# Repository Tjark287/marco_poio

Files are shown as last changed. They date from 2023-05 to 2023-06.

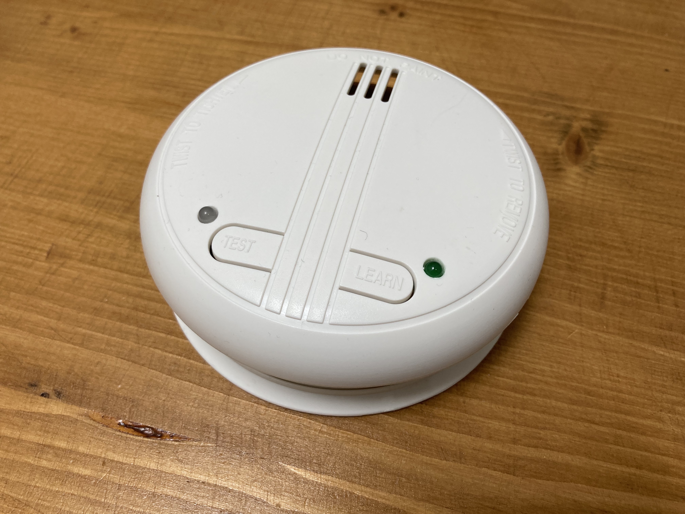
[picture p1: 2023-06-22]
Hardware/POI_Prototype.jpeg

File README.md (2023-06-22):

# Marco POIo Project

The goal of the "Marco POIo" project is to assist blind people in navigating back to a known spot where a point of interest (POI) has been left behind. The wearable device provides haptic feedback in the form of vibrations to guide the user towards the POI when the user presses a button. Additionally, the stationary device emits a beeping sound when the user gets within a specified distance of the POI. Both devices are equipped with GPS, a microcontroller unit (MCU) and an ISM transceiver. The wearable device also includes a magnetic sensor to act as a compass, helping the user to navigate towards the stationary device.

**Software overview:**
The main.c has two modes depending on loading the POI or the WEARABLE. Please use either the #define IS_POI or IS_WEARABLE depending on which device should be programmed. We used the minmea library by Kosma Moczek for nmea string decoding and partially ported the RFM69 library by Felix Rusu (LowPowerLab.com) to C for the ISM communications.

**Disclaimer:**
Please note that the project was created for a UNI project and is still in its early development phase. We do not recommend relying on the system as is for critical navigation purposes. We wish to improve on many areas, especially creating a more robust system for ISM communications, processing more of the available GPS NMEA sentences (currently only RMC processed) for a more stable location and a routine to calibrate the compass for more percise heading measurement as well as a generally improved system design.

**How To Build your own:**

*Hardware Components required:*
- Main Processor: STM32F411CEU - can vary, not much processing power is required
- GPS Receiver: L76-M33
- Radio: RFM69HW
- Antenna: helical antenna used, any 868MHz antenna with SWR<2 is good
- Magnetometer IC: MMC34160PJ
- 3V3 vibration motor
- 2x 2n7000 MOSFET
- LEDSs + resistors
- ST-Link V2 programmer

Please refer to the schematic for details.

## Prototype devices
For testing and in-class presentation we made 2 crude prototypes of our devices:
*POI:*
POI prototype
*Wearable:*
WEARABLE prototype

## How to use Marco POIo
The "Marco POIo" device consists of two parts: the Point of Interest (POI) and the WEARABLE. The POI is placed at a specific location, such as your clothing at the beach, while the WEARABLE is carried with you, for example, when you go swimming. The goal of the device is to help you find the POI once you come out of the water. Here is a detailed guide on how to use the device:

*1. Activating the POI:*
- Locate the POI and make sure it is turned on.
- Press the special power button on the POI. This will play a unique activation sound and activate the device.

*2. Preparing the WEARABLE before swimming:*
- Take the WEARABLE with you for swimming.
- Attach it as described.

*3. Using the WEARABLE during the return:*
- After swimming, when you come out of the water, press the button on the WEARABLE to start navigation mode.
- The WEARABLE starts vibrating to provide feedback.
- Hold the WEARABLE horizontally and point it in different directions to feel the vibration.
- The vibration becomes stronger when you align the WEARABLE towards your POI.
- Move in the direction where the vibration is strongest to find your way back to the POI.

*4. Approaching the POI:*
- As you get closer to the POI and are only a few meters away, the POI automatically starts beeping to help you locate it.

*5. Arrival and turning off the POI:*
- Once you reach the POI, press the button on it.
- This will stop the beeping, and the POI will automatically turn off.

Note: Make sure to activate the POI and Wearable, wait for the ready-beep and only then leave your spot. Please note that the device is still in the development phase and is not recommended for critical navigation situations. Do not rely solely on this device; use it as a support for your orientation.

## Design 
The development of the wearable focuses on finding the best wearing position, preferably on the wrist with a wrist strap or Velcro for ease of use. The wearable should be inexpensive and have Braille on the outside describing which way the device should be properly attached to the arm. It provides tactile feedback for navigation and a user-friendly interface.
The challenge is to develop a waterproof housing that is also light enough and does not interfere with signal transmission. Special materials, seals and coatings are being considered to prevent water ingress and ensure device performance.
Work is ongoing to develop and optimize the design to ensure the wearable is practical to implement and meets requirements. Consideration will be given to wearing position, accessibility through Braille, tactile feedback, water resistance, and ease of use. The goal is to create a wearable that provides an effective navigation solution for blind people while being comfortable and easy to use.

### Mockup Idea 1:
In this design idea, the wearable is attached to an arm holder by simply clicking it into the holder. After swimming, the wearable can be removed from the holder by a mechanical mechanism. It is activated by pressing a button. The elongated wearable then moves in front of itself like a blind stick. More intense vibration signals the user which direction to go.

### Mockup Idea 2:
The second design idea involves attaching the wearable to a wristwatch. The case of the wearable can be easily attached to any watch band. Braille on the case clarifies where the front and back are located. Once on the water, you hold your arm in front of you as if you were looking at the watch and press the button on the side of the case. Intense vibration signals the user which way to go.

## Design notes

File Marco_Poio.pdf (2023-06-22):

# ASSIST HEIDI

# Final Presentation

# MARCO POIo

Matthias Finding | | | ew21b031@technikum-wien.de
David Schmutz | | | ew21b083@technikum-wien.de
Tjark Neumann | | | if22x027@technikum-wien.de

### https://github.com/Tjark287/marco_poio

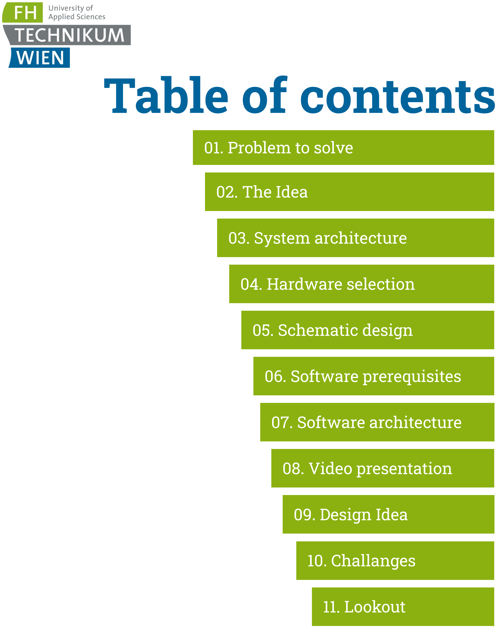
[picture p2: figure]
Table of contents; 01. Problem to solve; 02. The Idea; 03. System architecture; 04. Hardware selection; 05. Schematic design; 06. Software prerequisites; 07. Software architecture; 09. Design Idea; 08. Video presentation; 10. Challanges; 11. Lookout

# NEVER GET LOST SWIMMING AGAIN

### -MARCO POIO

# What is the problem to solve?

While blind people oftentimes develop amazing navigational skills on land,

### when they enter a body of water it becomes very hard to get an idea of

where you are due to currents carrying you away in unexpected ways.

# NEVER LOSE YOUR CLOTHE AGIAN

### -MARCO POIO

# How to solve the problem?

## The Idea

### 2-piece device:

### - Point of interest (POI) - Wearable

### Navigate with Wearable device to the POI device

# System architecture

## Overview

Wearable

GPS

B-Sensor

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
GPS receiver

Compass IC

ISM transceiver

Microcontroller

Interface devices
(Vibration-Motor, Button)

GPS receiver

ISM transceiver

Microcontroller

Interface devices
(Vibration-Motor, Button)

# Hardware selection

## Overview

To implement our system architecture, we chose the following components:

- GPS: Quectel L76-M33 GPS receiver
- ISM: HopeRF RFM69HW 868MHz +20dBm ISM transceiver
- Compass: MMC34160PJ ±16 Gauss magnetic sensor
- MCU: STM32F411CEU 100MHz ARM Cortex M4

All hardware components are 3V compatible

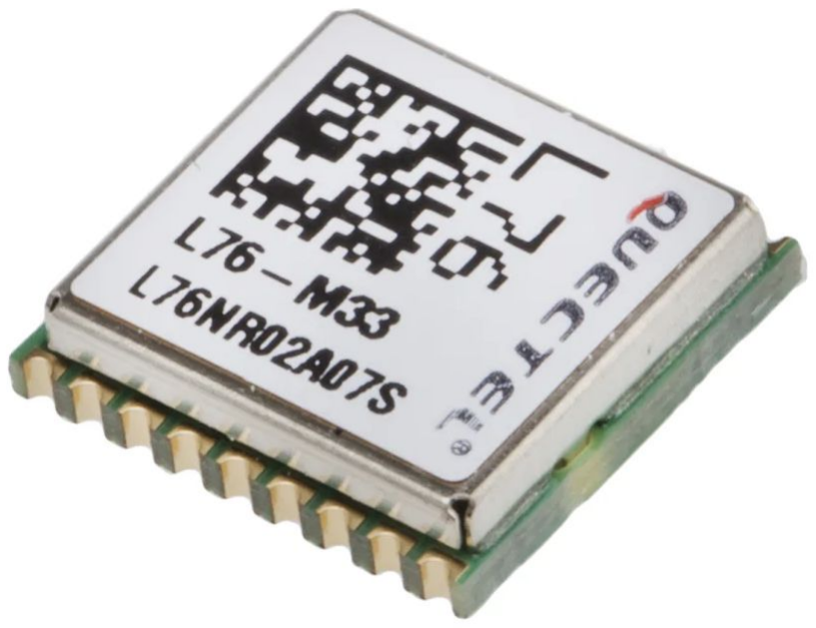
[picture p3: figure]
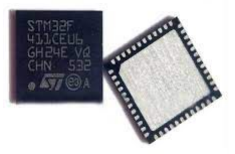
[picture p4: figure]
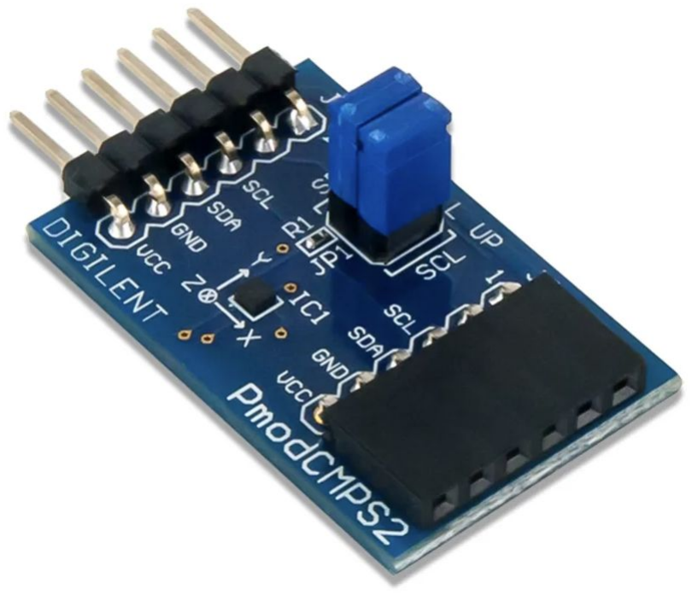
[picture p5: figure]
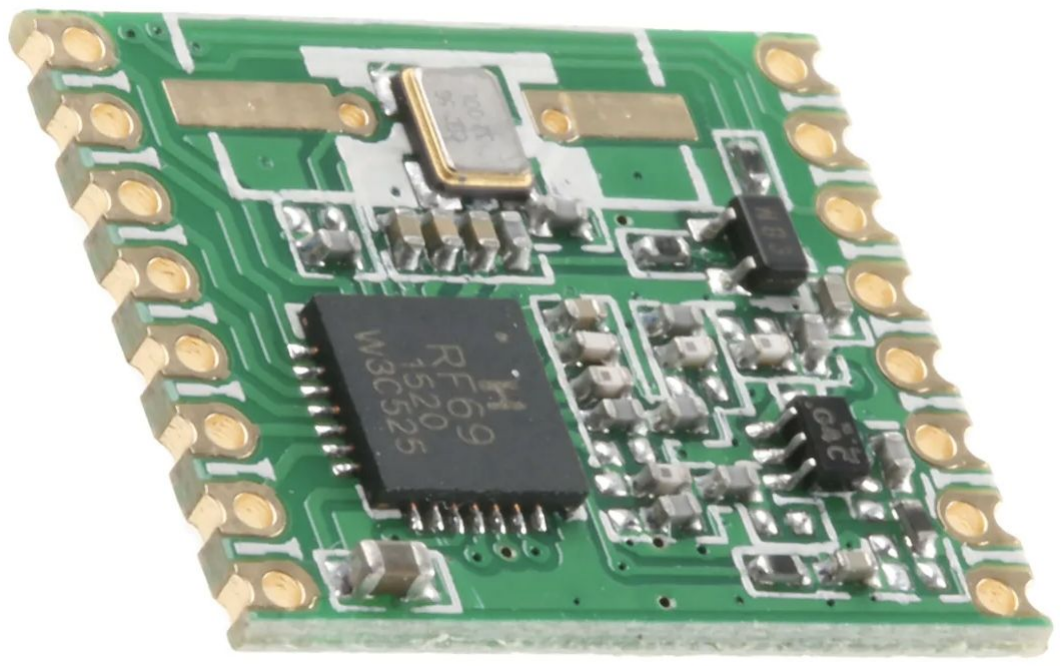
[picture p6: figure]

# Schematic design

## Overview

The schematic describes the connectivity of all hardware components in our design. The main interconnects are:

- GPS: UART interface to STM32 MCU (PB3, receive only)
- ISM: SPI interface + control pins to STM32 MCU (PA1, PA4, PA5, PA6, PA7)
- Compass: I2C interface to STM32 MCU (PB6, PB7)
- User interface:
- Pushbutton to interrupt pin on STM32 (PB1)
- PWM control of vibration-motor from STM32 (PA10)
- GPIO output for Buzzer activation from STM32 (PB9)

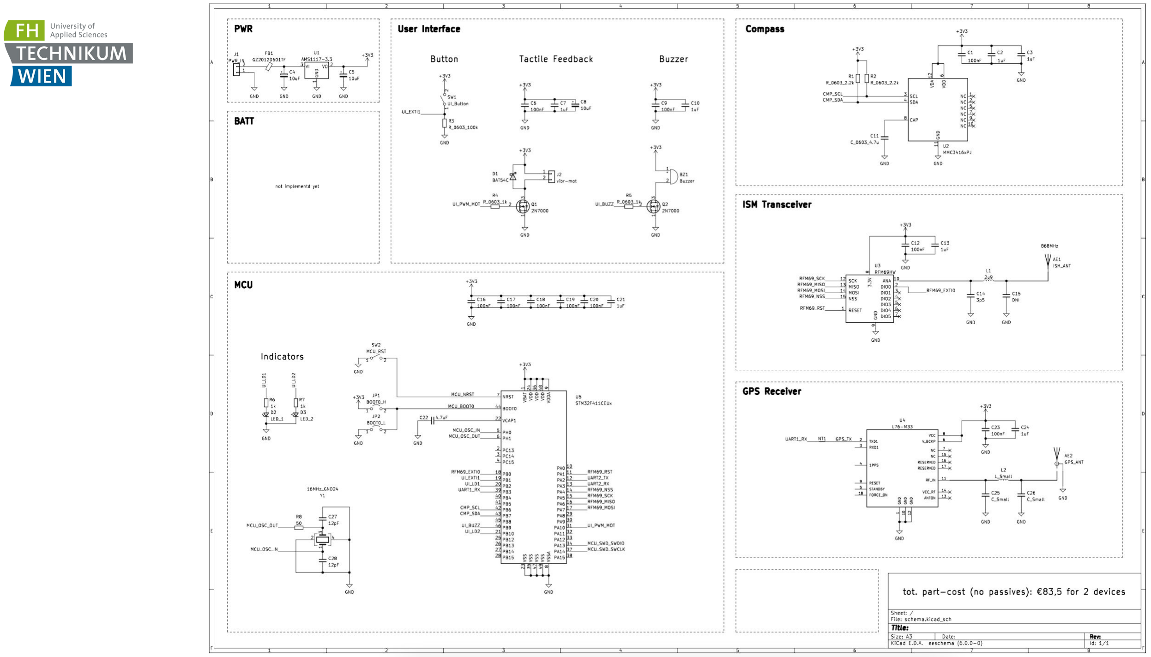
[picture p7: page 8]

# Software prerequisites

## Overview

External libraries used:

- minmea.c for GPS message decoding
- RFM69.c (ported from C++ to C) to handle the RF communications

Libraries created from scratch:

- helpHeidi.c
- gps.c
- compass.c

# Software architecture

## Overview

The architecture of the entire system is event- and timer-based. Three main callbacks were implemented:

- HAL_GPIO_EXTI_Callback: handles pushbutton input and interrupts from the RFM69 module
- HAL_UART_RxCpltCallback: handles information received from the GPS module
- HAL_TIM_PeriodElapsedCallback: handles events timed by the main 10Hz system timer

The main loop then carries out all data-send-operations and setting of vibration-motor and buzzer depending on the system state.

To further simplify the coding process, the target device and thereby the system behavior can be defined with a #define statement at the beginning of the code with:
#define IS_POI or #define IS_WEARABLE

# Video

## Prototype

# Design

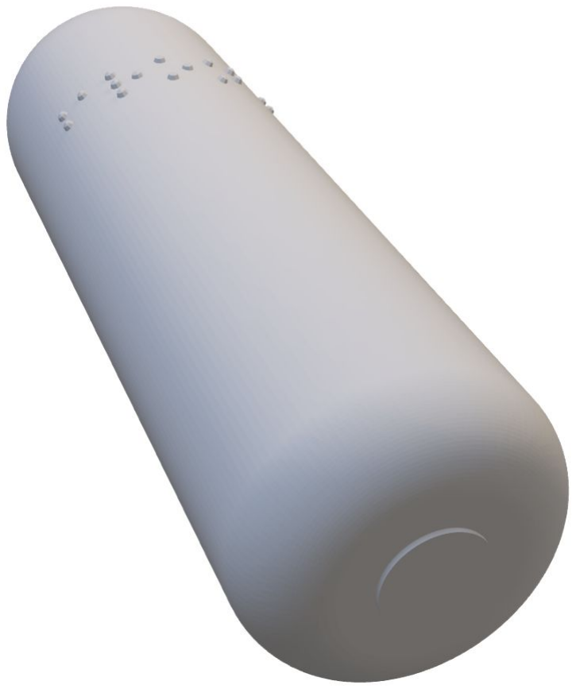
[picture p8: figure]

## Prerequisites

Accessibility (Cheap)

Braille Integration

Tactile Feedback

Waterproof

User-Friendly Interface

# Design

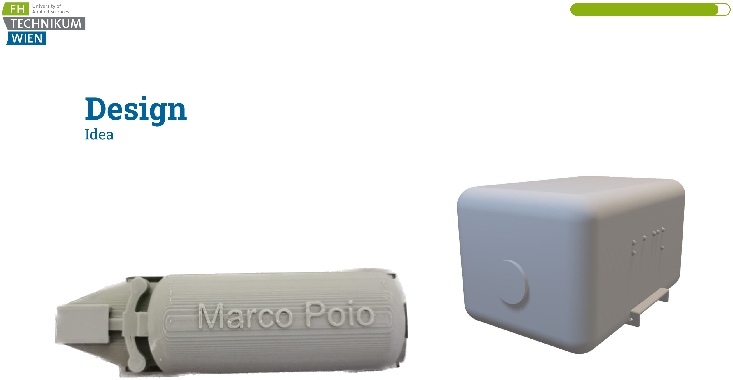
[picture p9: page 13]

## Idea

# Challenges

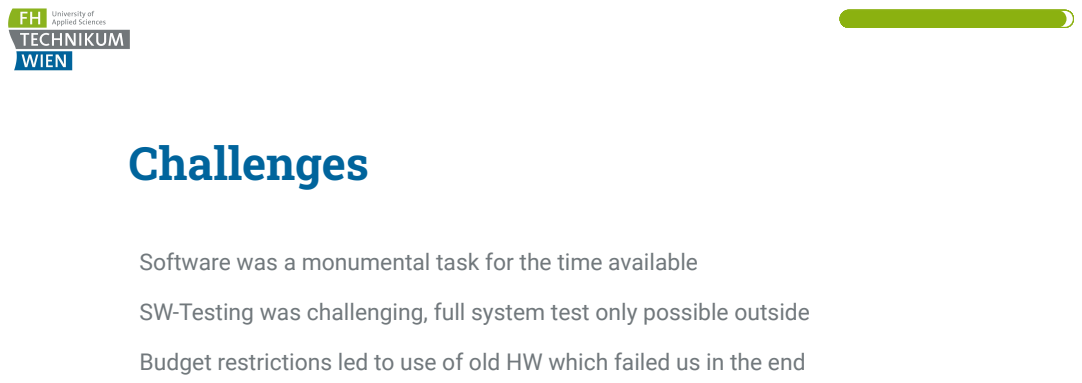
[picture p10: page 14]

Software was a monumental task for the time available

SW-Testing was challenging, full system test only possible outside

Budget restrictions led to use of old HW which failed us in the end

# Lookout

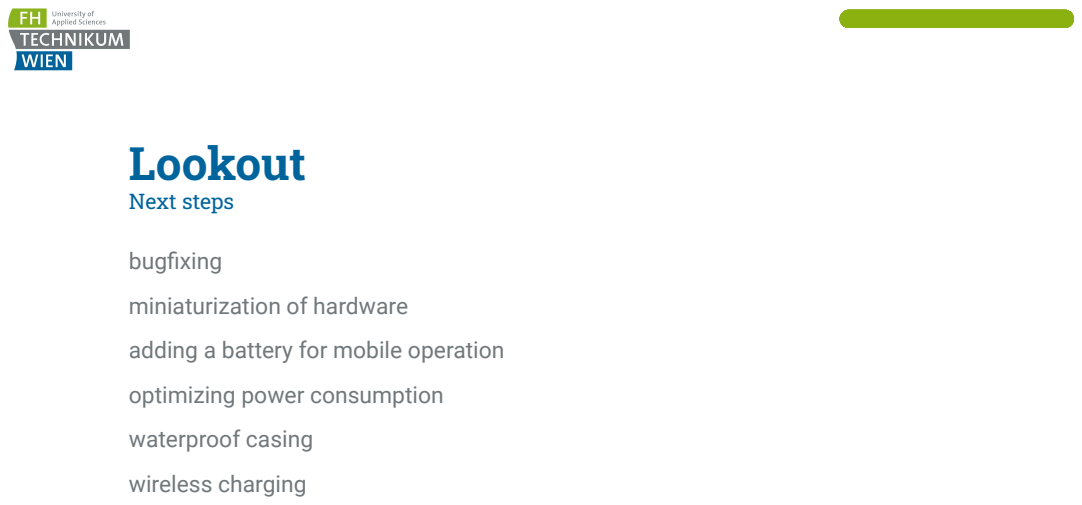
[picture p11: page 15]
Next steps; bugfixing; waterproof casing; wireless charging

miniaturization of hardware

adding a battery for mobile operation

optimizing power consumption

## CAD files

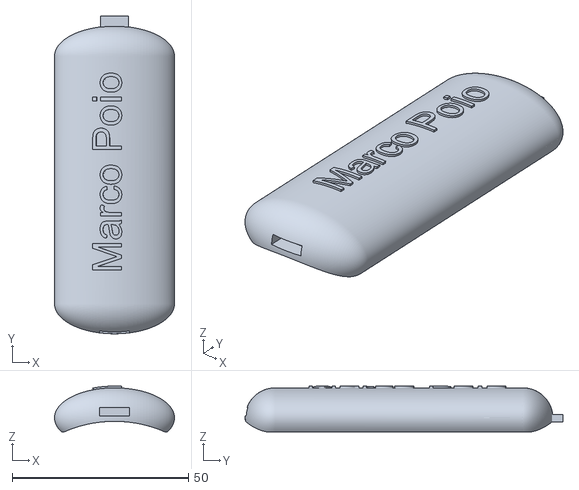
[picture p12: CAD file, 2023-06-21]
Design/Mockup Final Version 1/Marcopoio handheld.stl
34.0 x 90.0 x 13.0

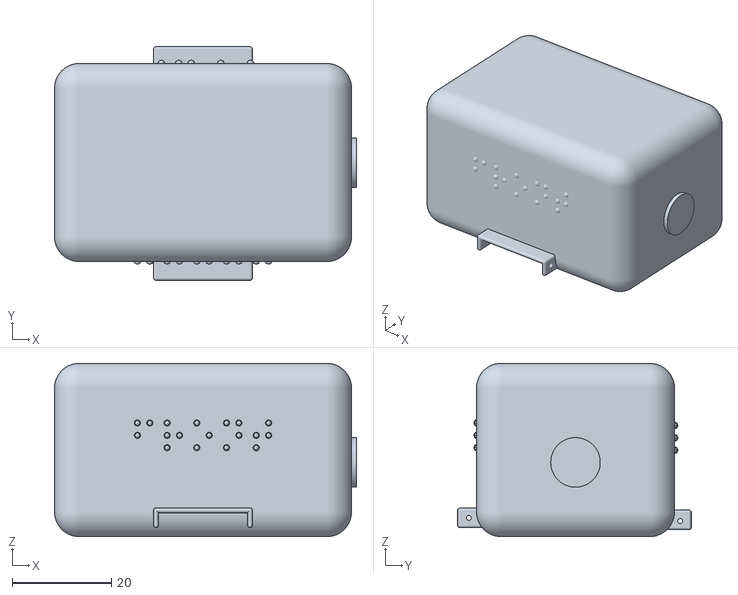
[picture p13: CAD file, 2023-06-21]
Design/Mockup Version 2/Marco_poio.stl
61.0 x 47.2 x 35.0

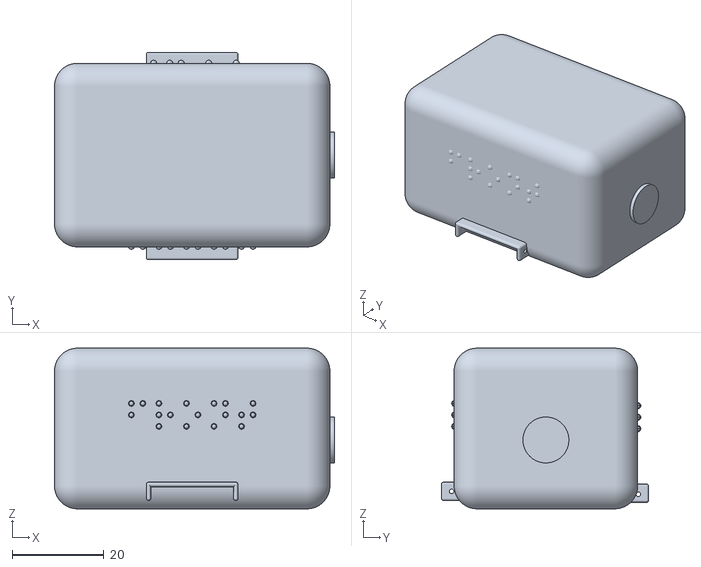
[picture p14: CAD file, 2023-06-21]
Hardware/Mockup Final Version 2/marco_poio_all.stl
61.0 x 45.2 x 35.0

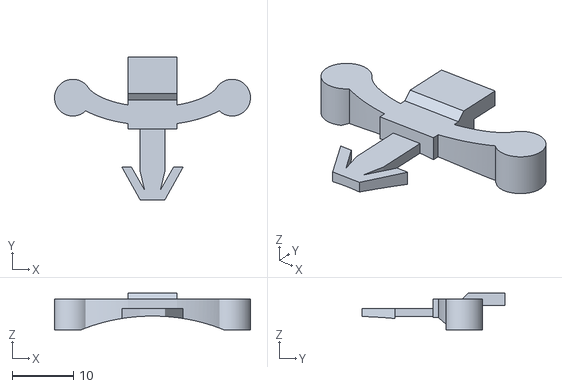
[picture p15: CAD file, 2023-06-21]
Design/Mockup Final Version 1/Marcopoio bayonettverschluss.stl
32.0 x 23.4 x 6.00

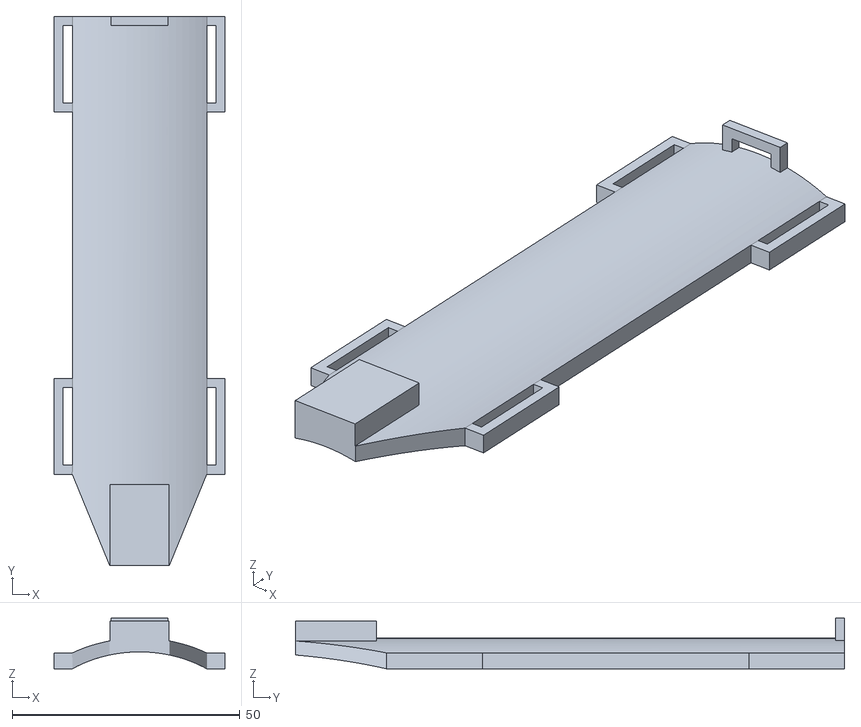
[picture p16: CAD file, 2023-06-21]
Design/Mockup Final Version 1/Marcopoio base.stl
37.5 x 120.4 x 11.1

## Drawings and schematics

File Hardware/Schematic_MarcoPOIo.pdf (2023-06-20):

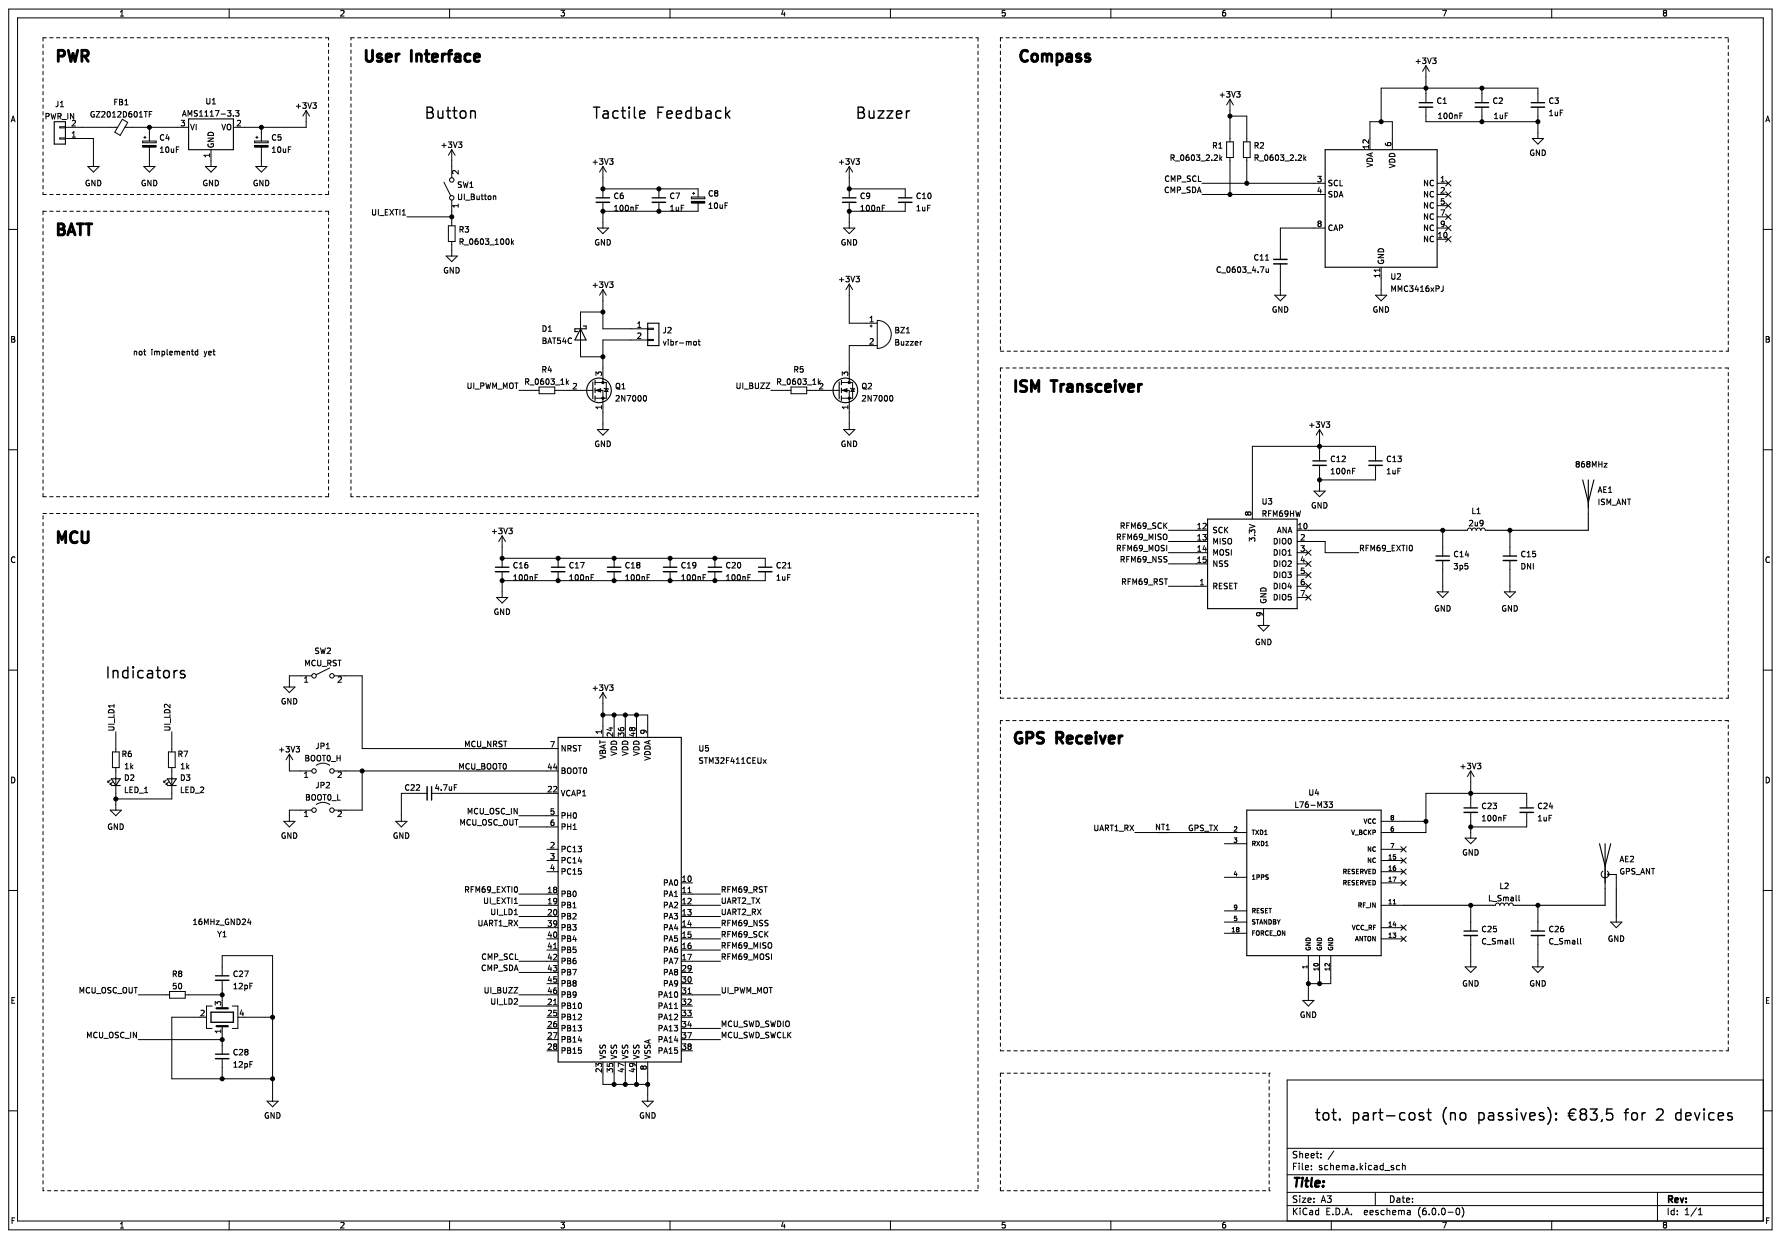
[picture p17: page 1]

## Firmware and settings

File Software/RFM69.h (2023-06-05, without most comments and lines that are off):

#define INC_RFM69_H_
extern SPI_HandleTypeDef hspi1;
uint8_t RFM69_readReg(uint8_t addr);
void RFM69_writeReg(uint8_t addr, uint8_t value);
int16_t RFM69_readRSSI(_Bool forceTrigger);
uint32_t millis();
void RFM69_setHighPowerRegs(_Bool enable);
void RFM69_setMode(uint8_t newMode);
_Bool RFM69_canSend();
void RFM69_receiveBegin();
void RFM69_interruptHandler();
_Bool RFM69_receiveDone();
void RFM69_sendFrame(uint16_t toAddress, const void* buffer, uint8_t bufferSize, _Bool requestACK, _Bool sendACK);
void RFM69_send(uint16_t toAddress, const void* buffer, uint8_t bufferSize, _Bool requestACK);
_Bool RFM69_ACKReceived(uint16_t fromNodeID);
_Bool RFM69_ACKRequested();
void RFM69_sendACK(const void* buffer, uint8_t bufferSize);
_Bool RFM69_sendWithRetry(uint16_t toAddress, const void* buffer, uint8_t bufferSize, uint8_t retries, uint8_t retryWaitTime);
void RFM69_setPowerLevel(uint8_t powerLevel);
void RFM69_setHighPower(_Bool _isRFM69HW_HCW);
void RFM69_encrypt(const char* key);
_Bool RFM69_initialize(uint8_t freqBand, uint16_t nodeID, uint8_t networkID);
uint32_t RFM69_getFrequency();
void RFM69_setFrequency(uint32_t freqHz);
uint8_t* RFM69_returnData();
void RFM69_havedata(_Bool havedata);
void RFM69_isSpy(_Bool amiaspy);
void RFM69_reset();
_Bool RFM69_isMode(uint8_t mode);
uint8_t RFM69_DataLen();
#define RF69_MAX_DATA_LEN       61 // to take advantage of the built in AES/CRC we want to limit the frame size to the internal FIFO size (66 bytes - 3 bytes overhead - 2 bytes crc)
#define CSMA_LIMIT              -10 // upper RX signal sensitivity threshold in dBm for carrier sense access
#define RF69_MODE_SLEEP         0 // XTAL OFF
#define RF69_MODE_STANDBY       1 // XTAL ON
#define RF69_MODE_SYNTH         2 // PLL ON
#define RF69_MODE_TX            3 // TX MODE
#define RF69_MODE_RX            4 // RX MODE
#define RF69_315MHZ            31 // non trivial values to avoid misconfiguration
#define RF69_433MHZ            43
#define RF69_868MHZ            86
#define RF69_915MHZ            91
#define null                  0
#define COURSE_TEMP_COEF    -90 // puts the temperature reading in the ballpark, user can fine tune the returned value
#define RF69_BROADCAST_ADDR   0
#define RF69_CSMA_LIMIT_MS 1000
#define RF69_TX_LIMIT_MS   1000
#define RF69_FSTEP  61.03515625 // == FXOSC / 2^19 = 32MHz / 2^19 (p13 in datasheet)
#define RFM69_CTL_SENDACK   0x80
#define RFM69_CTL_REQACK    0x40
#define RFM69_ACK_TIMEOUT   30  // 30ms roundtrip req for 61byte packets
#if defined(RF69_LISTENMODE_ENABLE)
  #define  DEFAULT_LISTEN_RX_US 256
  #define  DEFAULT_LISTEN_IDLE_US 1000000
#endif
#define REG_FIFO          0x00
#define REG_OPMODE        0x01
#define REG_DATAMODUL     0x02
#define REG_BITRATEMSB    0x03
#define REG_BITRATELSB    0x04
#define REG_FDEVMSB       0x05
#define REG_FDEVLSB       0x06
#define REG_FRFMSB        0x07
#define REG_FRFMID        0x08
#define REG_FRFLSB        0x09
#define REG_OSC1          0x0A
#define REG_AFCCTRL       0x0B
#define REG_LOWBAT        0x0C
#define REG_LISTEN1       0x0D
#define REG_LISTEN2       0x0E
#define REG_LISTEN3       0x0F
#define REG_VERSION       0x10
#define REG_PALEVEL       0x11
#define REG_PARAMP        0x12
#define REG_OCP           0x13
#define REG_AGCREF        0x14  // not present on RFM69/SX1231
#define REG_AGCTHRESH1    0x15  // not present on RFM69/SX1231
#define REG_AGCTHRESH2    0x16  // not present on RFM69/SX1231
#define REG_AGCTHRESH3    0x17  // not present on RFM69/SX1231
#define REG_LNA           0x18
#define REG_RXBW          0x19
#define REG_AFCBW         0x1A
#define REG_OOKPEAK       0x1B
#define REG_OOKAVG        0x1C
#define REG_OOKFIX        0x1D
#define REG_AFCFEI        0x1E
#define REG_AFCMSB        0x1F
#define REG_AFCLSB        0x20
#define REG_FEIMSB        0x21
#define REG_FEILSB        0x22
#define REG_RSSICONFIG    0x23
#define REG_RSSIVALUE     0x24
#define REG_DIOMAPPING1   0x25
#define REG_DIOMAPPING2   0x26
#define REG_IRQFLAGS1     0x27
#define REG_IRQFLAGS2     0x28
#define REG_RSSITHRESH    0x29
#define REG_RXTIMEOUT1    0x2A
#define REG_RXTIMEOUT2    0x2B
#define REG_PREAMBLEMSB   0x2C
#define REG_PREAMBLELSB   0x2D
#define REG_SYNCCONFIG    0x2E
#define REG_SYNCVALUE1    0x2F
#define REG_SYNCVALUE2    0x30
#define REG_SYNCVALUE3    0x31
#define REG_SYNCVALUE4    0x32
#define REG_SYNCVALUE5    0x33
#define REG_SYNCVALUE6    0x34
#define REG_SYNCVALUE7    0x35
#define REG_SYNCVALUE8    0x36
#define REG_PACKETCONFIG1 0x37
#define REG_PAYLOADLENGTH 0x38
#define REG_NODEADRS      0x39
#define REG_BROADCASTADRS 0x3A
#define REG_AUTOMODES     0x3B
#define REG_FIFOTHRESH    0x3C
#define REG_PACKETCONFIG2 0x3D
#define REG_AESKEY1       0x3E
#define REG_AESKEY2       0x3F
#define REG_AESKEY3       0x40
#define REG_AESKEY4       0x41
#define REG_AESKEY5       0x42
#define REG_AESKEY6       0x43
#define REG_AESKEY7       0x44
#define REG_AESKEY8       0x45
#define REG_AESKEY9       0x46
#define REG_AESKEY10      0x47
#define REG_AESKEY11      0x48
#define REG_AESKEY12      0x49
#define REG_AESKEY13      0x4A
#define REG_AESKEY14      0x4B
#define REG_AESKEY15      0x4C
#define REG_AESKEY16      0x4D
#define REG_TEMP1         0x4E
#define REG_TEMP2         0x4F
#define REG_TESTLNA       0x58
#define REG_TESTPA1       0x5A  // only present on RFM69HW/SX1231H
#define REG_TESTPA2       0x5C  // only present on RFM69HW/SX1231H
#define REG_TESTDAGC      0x6F
#define RF_OPMODE_SEQUENCER_OFF       0x80
#define RF_OPMODE_SEQUENCER_ON        0x00  // Default
#define RF_OPMODE_LISTEN_ON           0x40
#define RF_OPMODE_LISTEN_OFF          0x00  // Default
#define RF_OPMODE_LISTENABORT         0x20
#define RF_OPMODE_SLEEP               0x00
#define RF_OPMODE_STANDBY             0x04  // Default
#define RF_OPMODE_SYNTHESIZER         0x08
#define RF_OPMODE_TRANSMITTER         0x0C
#define RF_OPMODE_RECEIVER            0x10
#define RF_DATAMODUL_DATAMODE_PACKET            0x00  // Default
#define RF_DATAMODUL_DATAMODE_CONTINUOUS        0x40
#define RF_DATAMODUL_DATAMODE_CONTINUOUSNOBSYNC 0x60
#define RF_DATAMODUL_MODULATIONTYPE_FSK         0x00  // Default
#define RF_DATAMODUL_MODULATIONTYPE_OOK         0x08
#define RF_DATAMODUL_MODULATIONSHAPING_00       0x00  // Default
#define RF_DATAMODUL_MODULATIONSHAPING_01       0x01
#define RF_DATAMODUL_MODULATIONSHAPING_10       0x02
#define RF_DATAMODUL_MODULATIONSHAPING_11       0x03
#define RF_BITRATEMSB_1200            0x68
#define RF_BITRATELSB_1200            0x2B
#define RF_BITRATEMSB_2400            0x34
#define RF_BITRATELSB_2400            0x15
#define RF_BITRATEMSB_4800            0x1A  // Default
#define RF_BITRATELSB_4800            0x0B  // Default
#define RF_BITRATEMSB_9600            0x0D
#define RF_BITRATELSB_9600            0x05
#define RF_BITRATEMSB_19200           0x06
#define RF_BITRATELSB_19200           0x83
#define RF_BITRATEMSB_38400           0x03
#define RF_BITRATELSB_38400           0x41
#define RF_BITRATEMSB_38323           0x03
#define RF_BITRATELSB_38323           0x43
#define RF_BITRATEMSB_34482           0x03
#define RF_BITRATELSB_34482           0xA0
#define RF_BITRATEMSB_76800           0x01
#define RF_BITRATELSB_76800           0xA1
#define RF_BITRATEMSB_153600          0x00
#define RF_BITRATELSB_153600          0xD0
#define RF_BITRATEMSB_57600           0x02
#define RF_BITRATELSB_57600           0x2C
#define RF_BITRATEMSB_115200          0x01
#define RF_BITRATELSB_115200          0x16
#define RF_BITRATEMSB_12500           0x0A
#define RF_BITRATELSB_12500           0x00
#define RF_BITRATEMSB_25000           0x05
#define RF_BITRATELSB_25000           0x00
#define RF_BITRATEMSB_50000           0x02
#define RF_BITRATELSB_50000           0x80
#define RF_BITRATEMSB_100000          0x01
#define RF_BITRATELSB_100000          0x40
#define RF_BITRATEMSB_150000          0x00
#define RF_BITRATELSB_150000          0xD5
#define RF_BITRATEMSB_200000          0x00
#define RF_BITRATELSB_200000          0xA0
#define RF_BITRATEMSB_250000          0x00
#define RF_BITRATELSB_250000          0x80
#define RF_BITRATEMSB_300000          0x00
#define RF_BITRATELSB_300000          0x6B
#define RF_BITRATEMSB_32768           0x03
#define RF_BITRATELSB_32768           0xD1
#define RF_BITRATEMSB_55555           0x02
#define RF_BITRATELSB_55555           0x40
#define RF_BITRATEMSB_200KBPS         0x00
#define RF_BITRATELSB_200KBPS         0xa0
#define RF_FDEVMSB_2000             0x00
#define RF_FDEVLSB_2000             0x21
#define RF_FDEVMSB_5000             0x00  // Default
#define RF_FDEVLSB_5000             0x52  // Default
#define RF_FDEVMSB_7500             0x00
#define RF_FDEVLSB_7500             0x7B
#define RF_FDEVMSB_10000            0x00
#define RF_FDEVLSB_10000            0xA4
#define RF_FDEVMSB_15000            0x00
#define RF_FDEVLSB_15000            0xF6
#define RF_FDEVMSB_20000            0x01
#define RF_FDEVLSB_20000            0x48
#define RF_FDEVMSB_25000            0x01
#define RF_FDEVLSB_25000            0x9A
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

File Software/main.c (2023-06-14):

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
/* Includes ------------------------------------------------------------------*/
#include "main.h"

/* USER CODE BEGIN Includes */

#include<stdlib.h>
#include<string.h>
#include<stdio.h>
#include<stdbool.h>
#include "RFM69.h"
#include "helpHeidi.h"
#include "compass.h"
#include "gps.h"
#include "minmea.h"

/* USER CODE END Includes */

/* USER CODE BEGIN PTD */

/*
 * GPS data structure
 */

struct gpsdata{
	float lat, lon;
	uint8_t numsat;
};
typedef struct gpsdata gpsdata_t;

/* USER CODE END PTD */

I2C_HandleTypeDef hi2c1;

SPI_HandleTypeDef hspi1;

TIM_HandleTypeDef htim1;
TIM_HandleTypeDef htim2;
TIM_HandleTypeDef htim11;

UART_HandleTypeDef huart1;
UART_HandleTypeDef huart2;
DMA_HandleTypeDef hdma_usart1_rx;

/* USER CODE BEGIN PV */

/* DEVICE SELECTION ----------------------------------------------------------*/
/*	@brief uncomment POI or WEARABLE
*/

//#define IS_POI
#define IS_WEARABLE

/*
 * wireless communication setup
 */

#ifdef IS_POI
#define NODEID        3
#endif

#ifdef IS_WEARABLE
#define NODEID        2
#endif

/*
 * common wireless settings
 */

#define NETWORKID     100  //the same on all nodes that talk to each other
#define FREQUENCY     RF69_868MHZ
#define ENCRYPTKEY    "heidiheidiheidii" // exactly 16 characters/bytes
#define IS_RFM69HW_HCW

// Vibration off state
#define VIB_OFF 0

// UART buffer
#define UARTbufLen 75
char uartData[UARTbufLen];

// GPS data struct's
gpsdata_t myGPS, extGPS;

// init bools
_Bool haveReceived = false;
_Bool haveGPS = false;
_Bool GPSvalid = false;
_Bool txTimeout = false;
_Bool rxTimeout = false;
_Bool rfAvailable = false;

// txTimeout timer variable
uint8_t txTimeoutTim = 0;

/*
 * device-specific variables
 */

#ifdef IS_POI
// distance variable for buzzer activation
float distance;
#define DISTANCE_TO_BUZZ 15.0f
#endif

#ifdef IS_WEARABLE
// heading search mode state variable for wearable + timer variable
_Bool IS_headingMode = false; // init true for debug
uint16_t headingModeTim = 0;
#define HEADINGMODE_TIME 300 - 1 // time device remains in headingmode x100ms

// heading variable
float my_heading = 0.0;
#endif

/* USER CODE END PV */

void SystemClock_Config(void);
static void MX_GPIO_Init(void);
static void MX_DMA_Init(void);
static void MX_I2C1_Init(void);
static void MX_SPI1_Init(void);
static void MX_TIM1_Init(void);
static void MX_USART1_UART_Init(void);
static void MX_USART2_UART_Init(void);
static void MX_TIM2_Init(void);
static void MX_TIM11_Init(void);
/**
  * @brief  The application entry point.
  * @retval int
  */
int main(void)
{
  /* MCU Configuration--------------------------------------------------------*/

  /* Reset of all peripherals, Initializes the Flash interface and the Systick. */
  HAL_Init();

  /* Configure the system clock */
  SystemClock_Config();

  /* Initialize all configured peripherals */
  MX_GPIO_Init();
  MX_DMA_Init();
  MX_I2C1_Init();
  MX_SPI1_Init();
  MX_TIM1_Init();
  MX_USART1_UART_Init();
  MX_USART2_UART_Init();
  MX_TIM2_Init();
  MX_TIM11_Init();
  /* USER CODE BEGIN 2 */

  /*
   * device & peripheral initialization
   */

	// init of RFM69
	RFM69_reset();
	RFM69_initialize(RF69_868MHZ, NODEID, NETWORKID);
	// enable high power hardware -> RFM69HW
	RFM69_setHighPower(true);
	// start in RX Mode
	RFM69_setMode(RF69_MODE_RX);
	// spyMode ?
	RFM69_isSpy(true);
	// encryption
	RFM69_encrypt(ENCRYPTKEY);
	// begin receiving and interrupting
	RFM69_receiveBegin();

	// init of GPS
	extern char GPS_recBuffer[GPS_receiveLen];
	HAL_UART_Receive_DMA(&huart1, (uint8_t*)GPS_recBuffer, GPS_receiveLen); // new DMA based approach

	// init of 10Hz heartbeat timer (11)
	HAL_TIM_Base_Start_IT(&htim11);

	// init buzzer pin to off
	HAL_GPIO_WritePin(UI_BUZZ_GPIO_Port, UI_BUZZ_Pin, RESET);

	// zero out GPS variables
	myGPS.lat = 0.0f;
	myGPS.lon = 0.0f;
	extGPS.lat = 0.0f;
	extGPS.lon = 0.0f;

	/*
	 * wearable specific setup
	 */

	#ifdef IS_WEARABLE
	// init tim1 ch3 to zero output
	HAL_TIM_PWM_Start(&htim1, TIM_CHANNEL_3);
	TIM3->CCR3 = VIB_OFF;

	// init compass
	if(!CM_init()){
		sprintf(uartData, "compass init fail\r\n");
		HAL_UART_Transmit(&huart2, (uint8_t*)uartData, sizeof(uartData), 10);
	}
	#endif

  /* USER CODE END 2 */

  /* Infinite loop */
  /* USER CODE BEGIN WHILE */
  while (1)
  {

		// call data management function, proceed if data available
		if(rfAvailable && RFM69_receiveDone()){

			// read RSSI
			// int16_t rssi = RFM69_readRSSI(false);

			// get pointer to received data
			uint8_t* dataP = RFM69_returnData();

			// save received coords in external GPS variable
			extGPS.lat = combine_coords(dataP[0], dataP[1], dataP[2], dataP[3]);
			extGPS.lon = combine_coords(dataP[4], dataP[5], dataP[6], dataP[7]);

			// reset rfAvailable flag
			rfAvailable = false;

			// gets set on first received GPS data from other device
			if(extGPS.lat != 0.0f && extGPS.lon != 0.0f) haveReceived = true;
		}


		#ifdef IS_WEARABLE
		// wearable sends data, faster when in heading mode
		uint8_t sendLen = 8;
		if(GPSvalid && !txTimeout){
			uint8_t txData[sendLen];
			uint8_t d_lat, m_lat, s_lat, h_lat, d_lon, m_lon, s_lon, h_lon;
			uint16_t toAddress = 3;

			// split coords to integer for tx
			split_coords(myGPS.lat, &d_lat, &m_lat, &s_lat, &h_lat);
			split_coords(myGPS.lon, &d_lon, &m_lon, &s_lon, &h_lon);

			// assemble packet
			txData[0] = d_lat;
			txData[1] = m_lat;
			txData[2] = s_lat;
			txData[3] = h_lat;
			txData[4] = d_lon;
			txData[5] = m_lon;
			txData[6] = s_lon;
			txData[7] = h_lon;

			// send GPS data to other device
			RFM69_receiveBegin();

			if (RFM69_canSend()){

				// send data
				RFM69_send(toAddress, txData, sendLen, false);

				// enable timeout only if tx success
				//txTimeout = true;

				// start listening again
				RFM69_receiveBegin();
			}

			// enable timeout independend of tx success
			txTimeout = true;
		}

		if(IS_headingMode){

			// get my heading (-1.0f if invalid)
			float heading = CM_getheading();

			// set vibration if heading and GPS valid
			if(heading != -1.0f && haveGPS && haveReceived){
				float gpsHead = gps_to_heading(extGPS.lat, extGPS.lon, myGPS.lat, myGPS.lon);
				TIM1->CCR3 = setVibr(heading, gpsHead, 45.0);
			} else {
				// turn motor off
				TIM1->CCR3 = VIB_OFF;
			}
		} else {
			// turn motor off
			TIM1->CCR3 = VIB_OFF;
		}
		#endif

		#ifdef IS_POI
		if(GPSvalid && !txTimeout){
			uint8_t sendLen = 8;
			uint8_t txData[sendLen];
			uint8_t d_lat, m_lat, s_lat, h_lat, d_lon, m_lon, s_lon, h_lon;
			uint16_t toAddress = 2;

			// split coords to integer for tx
			split_coords(myGPS.lat, &d_lat, &m_lat, &s_lat, &h_lat);
			split_coords(myGPS.lon, &d_lon, &m_lon, &s_lon, &h_lon);

			// assemble packet
			txData[0] = d_lat;
			txData[1] = m_lat;
			txData[2] = s_lat;
			txData[3] = h_lat;
			txData[4] = d_lon;
			txData[5] = m_lon;
			txData[6] = s_lon;
			txData[7] = h_lon;

			// send GPS data to other device
			RFM69_setMode(RF69_MODE_RX);

			if (RFM69_canSend()){

				// send data
				RFM69_send(toAddress, txData, sendLen, false);

				// Debug message
				sprintf(uartData, "\nTX Complete\r\n");
				HAL_UART_Transmit(&huart2, (uint8_t*)uartData, sizeof(uartData), 10);

				// start tx
				RFM69_setMode(RF69_MODE_TX);
			}

			// put RFM69 back in receive mode, listen for more
			RFM69_receiveBegin();

			// reset timeToSend bool
			txTimeout = true;
		}
		// set buzzer if wearable is near
		if(haveGPS && haveReceived){
			// check distance
			if(get_distance(myGPS.lat, myGPS.lon, extGPS.lat, extGPS.lon) < DISTANCE_TO_BUZZ){
				// Buzzer on
				HAL_GPIO_WritePin(UI_BUZZ_GPIO_Port, UI_BUZZ_Pin, SET);
			} else {
				// Buzzer off
				HAL_GPIO_WritePin(UI_BUZZ_GPIO_Port, UI_BUZZ_Pin, RESET);

			}
		}
		#endif


    /* USER CODE END WHILE */

    /* USER CODE BEGIN 3 */

  }
  /* USER CODE END 3 */
}

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
/* USER CODE BEGIN 4 */
void HAL_GPIO_EXTI_Callback(uint16_t GPIO_Pin)
{
	/*
	 * RFM69 interrupt handler;
	 * on RFM69 interrupt pin callback, process received data.
	 */

    // user button interrupt
    if(GPIO_Pin == GPIO_PIN_1)
    {
		#ifdef IS_WEARABLE
		IS_headingMode = true;
		#endif
		return;
    }

    // RFM69 packet received interrupt
    if(GPIO_Pin == GPIO_PIN_0 && RFM69_isMode(RF69_MODE_RX))
    {
    	// set "_havedata" to true
    	RFM69_havedata(true);
    	rfAvailable = true;
    }

}

void HAL_UART_RxCpltCallback(UART_HandleTypeDef *huart)
{
	extern char GPS_recBuffer[GPS_receiveLen];
	float lat, lon;
	uint8_t numsat;
	char rmcline[MINMEA_MAX_SENTENCE_LENGTH];

	// enable UART rx timeout
	rxTimeout = true;

	// if gnrmc line found, process line and validate GPS
	if(get_gnrmc_line(GPS_recBuffer, rmcline, MINMEA_MAX_SENTENCE_LENGTH)){
		GPSvalid = GPS_process(rmcline, &lat, &lon, &numsat);
	}

	if(GPSvalid){
		// sets haveGps true on first valid receive
		haveGPS = true;

		// save data only if valid
		myGPS.lat = lat;
		myGPS.lon = lon;
		myGPS.numsat = numsat;
	}
}


void HAL_TIM_PeriodElapsedCallback(TIM_HandleTypeDef *htim)
{
	if (htim == &htim2)
	{
		// 250ms TIMER - UNUSED
	}

	// 10Hz timer (tim11)
	if (htim == &htim11){

		// indicator LED
		if(haveGPS && haveReceived){
			HAL_GPIO_WritePin(LD_1_GPIO_Port, LD_1_Pin, SET);
		} else {
			HAL_GPIO_WritePin(LD_1_GPIO_Port, LD_1_Pin, RESET);
		}

		// heartbeat LED
		HAL_GPIO_TogglePin(LD_2_GPIO_Port, LD_2_Pin);


		// reset timeout and start UART receive again
		extern char GPS_recBuffer[GPS_receiveLen];
		static uint8_t uartCounter;

		if(rxTimeout){
			if(uartCounter++ > 5){
				rxTimeout = false;
				uartCounter = 0;
				HAL_UART_Receive_DMA(&huart1, (uint8_t*)GPS_recBuffer, GPS_receiveLen);
			}
		}

		// reset tx timeout depending on mode
		if(txTimeout){
			if (txTimeoutTim++ > 9){
				txTimeout = false;
				txTimeoutTim = 0;
			}
		}

		#ifdef IS_WEARABLE
		// reset heading mode timer
		if(IS_headingMode){
			if(headingModeTim++ > HEADINGMODE_TIME){
				IS_headingMode = false;
				headingModeTim = 0;
			}
	    }
		#endif

	}
}
/* USER CODE END 4 */
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


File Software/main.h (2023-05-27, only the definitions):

#define RFM69_RST_Pin GPIO_PIN_1
#define RFM69_RST_GPIO_Port GPIOA
#define RFM69_NSS_Pin GPIO_PIN_4
#define RFM69_NSS_GPIO_Port GPIOA
#define LD_1_Pin GPIO_PIN_2
#define LD_1_GPIO_Port GPIOB
#define LD_2_Pin GPIO_PIN_10
#define LD_2_GPIO_Port GPIOB
#define GPS_RST_Pin GPIO_PIN_13
#define GPS_RST_GPIO_Port GPIOB
#define GPS_FON_Pin GPIO_PIN_14
#define GPS_FON_GPIO_Port GPIOB
#define GPS_STDBY_Pin GPIO_PIN_15
#define GPS_STDBY_GPIO_Port GPIOB
#define UI_BUZZ_Pin GPIO_PIN_9
#define UI_BUZZ_GPIO_Port GPIOB

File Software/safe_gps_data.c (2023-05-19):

float GlobalLatitude;
float GlobalLongitude;
int GlobalSatellite;

String receivedData; // Variable for store the received data

void setup() {
  Serial.begin(9600); 
}

void loop() {
  
  if (Serial.available()) {
    char c = Serial.read(); // Read a single character from the serial interface
    receivedData += c; // Add received data to receivedData

    //receivedData = "$GPGGA,145509.000,4813.4212,N,01622.9795,E,6,2,99.99,251.0,M,43.4,M,,*6E";
    // Check if a complete Data-set is received 
    if (c == '\n') {
      // Check if its a GPGGA Data
      if (receivedData.startsWith("$GPGGA")) {

        firstTryToGetVaribalen(receivedData);
        secondTryTosafeGPGGA(receivedData);
        receivedData = "";
      }
      if (receivedData.startsWith("$GPGSA")) {
        // check 2D or 3D Mode
      }
    }

  }
}

// should safe Latitude, Longitude, Satellite Anzahl 
void firstTryToGetVaribalen(String gpggaStr ){

        // Latitude 
        String latitudeStr = gpggaStr.substring(18, 28);
        float latitude = latitudeStr.toFloat(); 
        // Longitude
        String longitudeStr = gpggaStr.substring(30, 42);
        float longitude = longitudeStr.toFloat(); 
        // Satellite
        String satelliteStr = gpggaStr.substring(45, 46);
        int satellite = satelliteStr.toInt(); 

        // safe variable global
        float GlobalLatitude = latitude;
        float GlobalLongitude = longitude;
        int GlobalSatellite = satellite;

        // serial Monitor
        Serial.print("Latitude: ");
        Serial.println(latitude, 4);

        Serial.print("Longitude: ");
        Serial.println(longitude, 4);

        Serial.print("Satellite: ");
        Serial.println(satellite); 
}

//  safe all Elemenets of the String in an Array
void secondTryTosafeGPGGA(String gpggaStr){
 
  
  String gpggaArray[15]; // Array zur Speicherung der Elemente

  int startIndex = 0;
  int elementIndex = 0;
  int commaIndex;

  // Schleife, um die Elemente zu extrahieren
  while ((commaIndex = gpggaStr.indexOf(',', startIndex)) != -1) {
    String element = gpggaStr.substring(startIndex, commaIndex); // Extrahiere das Element
    gpggaArray[elementIndex] = element; // Speichere das Element im Array
    elementIndex++;

    startIndex = commaIndex + 1;
  }

  // Letztes Element speichern
  String lastElement = gpggaStr.substring(startIndex); 
  gpggaArray[elementIndex] = lastElement;

  // Ausgabe der gespeicherten Elemente
  for (int i = 0; i < 15; i++) {
    Serial.print("Element ");
    Serial.print(i);
    Serial.print(": ");
    Serial.println(gpggaArray[i]);
  }



}






// Ohne Serial read
//________________________________________________________________________________________________//



float GlobalLatitude;
float GlobalLongitude;
int GlobalSatellite;

String receivedData; // Variable for store the received data

void setup() {
  Serial.begin(9600); 
}

void loop() {
  
receivedData = "$GPGGA,145509.000,4813.4212,N,01622.9795,E,6,2,99.99,251.0,M,43.4,M,,*6E";

      if (receivedData.startsWith("$GPGGA")) {

        firstTryToGetVaribalen(receivedData);
        secondTryTosafeGPGGA(receivedData);
        receivedData = "";


  }
}

// should safe Latitude, Longitude, Satellite Anzahl 
void firstTryToGetVaribalen(String gpggaStr ){

        // Latitude 
        String latitudeStr = gpggaStr.substring(18, 27);
        float latitude = latitudeStr.toFloat(); 
        // Longitude
        String longitudeStr = gpggaStr.substring(30, 42);
        float longitude = longitudeStr.toFloat(); 
        // Satellite
        String satelliteStr = gpggaStr.substring(45, 46);
        int satellite = satelliteStr.toInt(); 

        // safe variable global
        float GlobalLatitude = latitude;
        float GlobalLongitude = longitude;
        int GlobalSatellite = satellite;

        // serial Monitor
        Serial.print("Latitude: ");
        Serial.println(latitude, 4); //  6 Dezimalstellen begrenzen

        Serial.print("Longitude: ");
        Serial.println(longitude, 4); // 6 Dezimalstellen begrenzen

        Serial.print("Satellite: ");
        Serial.println(satellite); 

}

// should safe all Elemenets out of the String 
void secondTryTosafeGPGGA(String gpggaStr){
 
  
  String gpggaArray[15]; // Array zur Speicherung der Elemente

  int startIndex = 0;
  int elementIndex = 0;
  int commaIndex;

  // Schleife, um die Elemente zu extrahieren
  while ((commaIndex = gpggaStr.indexOf(',', startIndex)) != -1) {
    String element = gpggaStr.substring(startIndex, commaIndex); // Extrahiere das Element
    gpggaArray[elementIndex] = element; // Speichere das Element im Array
    elementIndex++;

    startIndex = commaIndex + 1;
  }

  // Letztes Element speichern
  String lastElement = gpggaStr.substring(startIndex); 
  gpggaArray[elementIndex] = lastElement;

  // Ausgabe der gespeicherten Elemente
  for (int i = 0; i < 15; i++) {
    Serial.print("Element ");
    Serial.print(i);
    Serial.print(": ");
    Serial.println(gpggaArray[i]);
  }
    // Values we need 
  String LatitudeStr = gpggaArray[2];
  String LongitudeStr = gpggaArray[4];
  String SatelliteStr = gpggaArray[7];

}

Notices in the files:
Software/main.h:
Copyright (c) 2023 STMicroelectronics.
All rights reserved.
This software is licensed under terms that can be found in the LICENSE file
